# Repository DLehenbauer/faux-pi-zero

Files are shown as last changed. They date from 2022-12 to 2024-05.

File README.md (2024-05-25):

# Faux Pi Zero

Open hardware RP2040 dev board in a Raspberry Pi Zero compatible form factor.  Includes Mini HDMI (via [bitbanged DVI](https://github.com/Wren6991/PicoDVI)) and microSD.

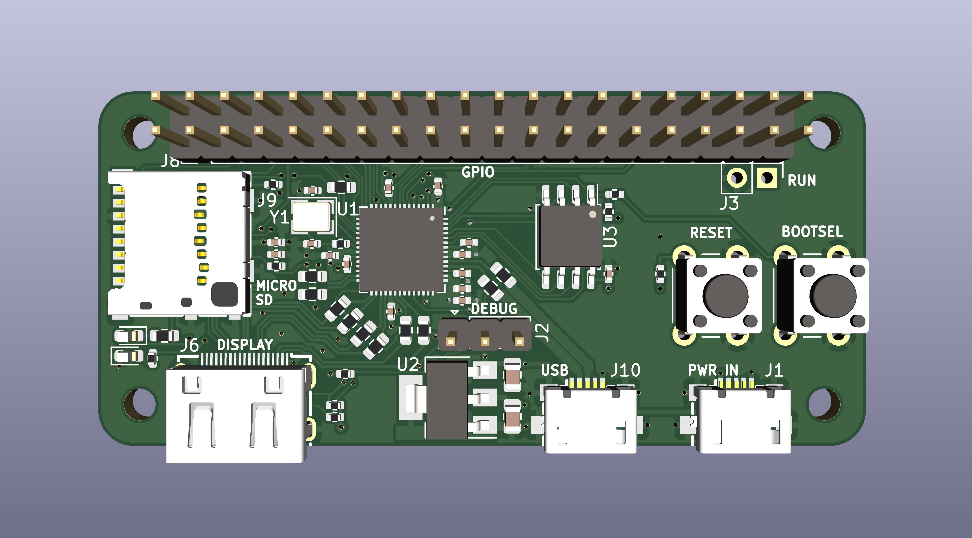
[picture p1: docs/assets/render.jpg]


## Description

This board aids with migrating a project from the Pi Zero to the RP2040 while retaining the option of moving back to the Pi Zero in the future.  It has the same footprint as the Pi Zero and a partially compatible [pinout](#pinout), making it convenient to support both the RP2040 and Pi Zero in the same design.

## Status

Works, but 1 of 2 boards received by JLCPCB had a solder bridge on the RP2040.  Looking at JLCPCB's EasyEDA footprints, it looks like JLCPCB used longer pads for the RP2040.  I'd recommend using a custom footprint and extending the pads, which hopefully will avoid defects.

A couple other things I'd change in retrospect:
* Expose UART TX/RX on the debug header and reorder pins so you can plug a [picoprobe](https://github.com/raspberrypi/picoprobe) into the board w/o wires.
* Remove the hacky activity LED from the microSD since [the lib](https://github.com/carlk3/no-OS-FatFS-SD-SPI-RPi-Pico) already blinks GP25.
* Try for a 2 layer board to reduce cost
* Reduce buttons to 6 x 3.5 and maybe try to squeeze in an optional wireless module

DVI and microSD both appear to work with a basic test.  I've exercised DVI, USB (host), SPI1, and the debug header quite a bit (all good).  Other functionality is either lightly tested or untested.

## Features

* Compatible footprint:
  * Mini HDMI (via [bitbanged DVI](https://github.com/Wren6991/PicoDVI))
  * Micro SD (via SPI mode.  Cards must be <2TB)
  * Micro USB
  * Power (via Micro USB)
* Partially compatible [pinout](#pinout)
* 16MB Flash
* Green status LED on GP25 (same as Pico)
* Red SD activity LED on GP9
* BOOTSEL and RESET buttons
* SWD Header

## Pinout

See [schematic](#schematic) for more details.



### Mapping from Pi Zero to Faux Px Zero

Pi Pin | Pico Pin | Pi GPIO | Pico GP | Function | Notes
-|-|-|-|-|-
1, 17 | 36 |  | 3V3 (Out) |  |
2, 4 | 39 |  | VSYS |  |
2, 4 | 40 |  | VBUS |  |
3 | 4 | GPIO 02 | GP 02 | I2C_SDA |
5 | 5 | GPIO 03 | GP 03 | I2C_SCL |
6, 9, 14, 20, 25, 30, 34, 39 | 3, 8, 13, 18, 23, 28, 33, 38, DBG-2 |  | GND |  |
7 |  | GPIO 04 | GP 24 |  |
8 | 1 | GPIO 14 | GP 00 | UART0 TX |
10 | 2 | GPIO 15 | GP 01 | UART0 RX |
11 | 12 | GPIO 17 | GP 09 | SD_CSn | Can be used as GP with SD card removed.  Note 10k pullup.
12 | 17 | GPIO 18 | GP 13 | SPI1_CSn | Can be used to share SPI1 with SD card.
13 | 11 | GPIO 27 | GP 08 | SD_DET | Can be used as GP with SD card removed.
15 | 14 | GPIO 22 | GP 10 | DVI_CEC | DVI_CEC when JP3 closed.  See [schematic](#schematic).
16 | 15 | GPIO 23 | GP 11 |  |
18 | DBG-3 | GPIO 24 | SWD |  |
19 | 6/10 | GPIO 10 | GP 04/07 | SPI0_RX/TX | Select [controller](https://www.oshwa.org/a-resolution-to-redefine-spi-signal-names/) or [peripheral](https://www.oshwa.org/a-resolution-to-redefine-spi-signal-names/) via JP1 and JP2.  See [schematic](#schematic).
21 | 10/6 | GPIO 09 | GP 07/04 | SPI0_TX/RX | Select [controller](https://www.oshwa.org/a-resolution-to-redefine-spi-signal-names/) or [peripheral](https://www.oshwa.org/a-resolution-to-redefine-spi-signal-names/) via JP1 and JP2.  See [schematic](#schematic).
22 | DBG-1 | GPIO 25 | SWCLK |  |
23 | 9 | GPIO 11 | GP 06 | SPI0_SCLK |
24 | 7 | GPIO 08 | GP 05 | SPI0_CSn |
26 |  | GPIO 07 |  |  |
27 | 34 | GPIO 00 | GP 28 | I2C_SCL | DVI_SDA when JP4 closed.  See [schematic](#schematic).
28 |  | GPIO 01 | GP 29 |  |
29 | 31 | GPIO 05 | GP 26 |  |
31 | 32 | GPIO 06 | GP 27 | I2C_SDA | DVI_SDA when JP5 closed.  See [schematic](#schematic).
32 |  | GPIO 12 |  |  |
33 |  | GPIO 13 |  |  |
35 | 16 | GPIO 19 | GP 12 | SPI1_RX / SD_DAT | Can be used as GP with SD card removed.  Note 10k pullup.
36 |  | GPIO 16 | BOOTSEL |  |
37 | 30 | GPIO 26 | RUN |  |
38 | 20 | GPIO 20 | GP 15 | SPI1_TX / SD_CMD | Can be used as GP with SD card removed.
40 | 19 | GPIO 21 | GP 14 | SPI1_SCLK / SD_CLK | Can be used as GP with SD card removed.
   |    |    | GP 23 | DVI_D2+ |
   |    | 21 | GP 16 | DVI_CK- |
   |    | 22 | GP 17 | DVI_CK+ |
   |    | 24 | GP 18 | DVI_D0- |
   |    | 25 | GP 19 | DVI_D0+ |
   |    | 26 | GP 20 | DVI_D1- |
   |    | 27 | GP 21 | DVI_D1+ |
   |    | 29 | GP 22 | DVI_D2- |
   | 35 |  | N/C |  |
   | 37 |  | 3V3_EN |  |
   | LED |  | GP 25 |  |

## Schematic

(Click image to view PDF)

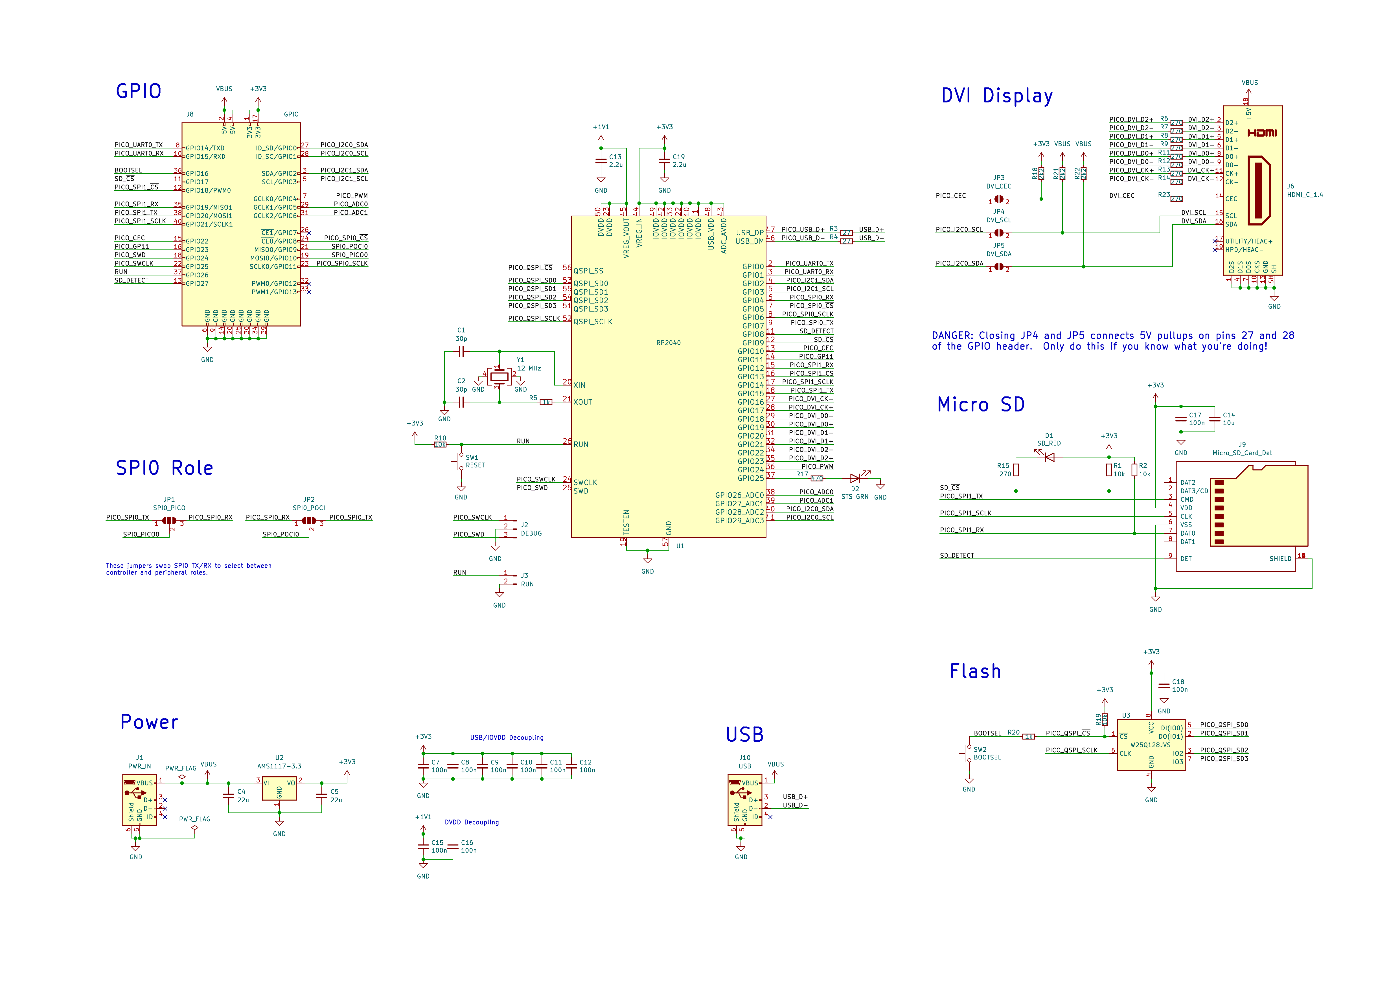
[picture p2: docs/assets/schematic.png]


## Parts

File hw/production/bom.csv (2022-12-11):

Designator | Footprint | Quantity | Value | LCSC Part #
C1, C2 | C_0402_1005Metric | 2 | 30p | C1570
C10, C11, C12, C15, C16, C17, C18, C7, C8, C9 | C_0402_1005Metric | 10 | 100n | C1525
C13, C19 | C_0402_1005Metric | 2 | 2.2u | C12530
C14 | C_0402_1005Metric | 1 | 10u | C15525
C4, C5 | C_0805_2012Metric | 2 | 22u | C45783
D1 | LED_0603_1608Metric | 1 | SD_RED | C2286
D2 | LED_0603_1608Metric | 1 | STS_GRN | C72043
J1 | MICRO-USB_MICRO-USB-17 | 1 | PWR_IN | C77238
J10 | MICRO-USB_MICRO-USB-17 | 1 | USB | C77238
J2 | PinHeader_1x03_P2.54mm_Vertical | 1 | DEBUG
J3 | PinHeader_1x02_P2.54mm_Vertical | 1 | RUN
J6 | HDMI-SMD_HDMI-201 | 1 | HDMI_C_1.4 | C720618
J8 | PinHeader_2x20_P2.54mm_Vertical | 1 | GPIO
J9 | SIM-SMD_8P-1040310811 | 1 | Micro_SD_Card_Det | C585350
JP1 | SolderJumper-3_P1.3mm_Open_RoundedPad1.0x1.5mm | 1 | SPI0_PICO
JP3 | SolderJumper-3_P1.3mm_Open_RoundedPad1.0x1.5mm | 1 | SPI0_POCI
JP7 | SolderJumper-2_P1.3mm_Open_RoundedPad1.0x1.5mm | 1 | DVI_CEC
JP8 | SolderJumper-2_P1.3mm_Open_RoundedPad1.0x1.5mm | 1 | DVI_SCL
JP9 | SolderJumper-2_P1.3mm_Open_RoundedPad1.0x1.5mm | 1 | DVI_SDA
R1, R10, R19, R2 | R_0402_1005Metric | 4 | 10k | C25744
R11, R12, R13, R14, R15, R23, R6, R7, R8, R9 | R_0603_1608Metric | 10 | 270 | C22966
R17 | R_0402_1005Metric | 1 | 470 | C25117
R18, R21, R22 | R_0402_1005Metric | 3 | 2k2 | C25879
R20, R5 | R_0402_1005Metric | 2 | 1k | C11702
R3, R4 | R_0603_1608Metric | 2 | 27 | C25190
SW1 | SW_PUSH_6mm | 1 | RESET
SW2 | SW_PUSH_6mm | 1 | BOOTSEL
U1 | QFN-56-1EP_7x7mm_P0.4mm_EP3.2x3.2mm_ThermalVias | 1 | RP2040 | C2040
U2 | SOT-223-3_TabPin2 | 1 | AMS1117-3.3 | C6186
U3 | SOIC-8_5.23x5.23mm_P1.27mm | 1 | W25Q128JVS | C97521
Y1 | Crystal_SMD_3225-4Pin_3.2x2.5mm | 1 | 12 MHz | C9002

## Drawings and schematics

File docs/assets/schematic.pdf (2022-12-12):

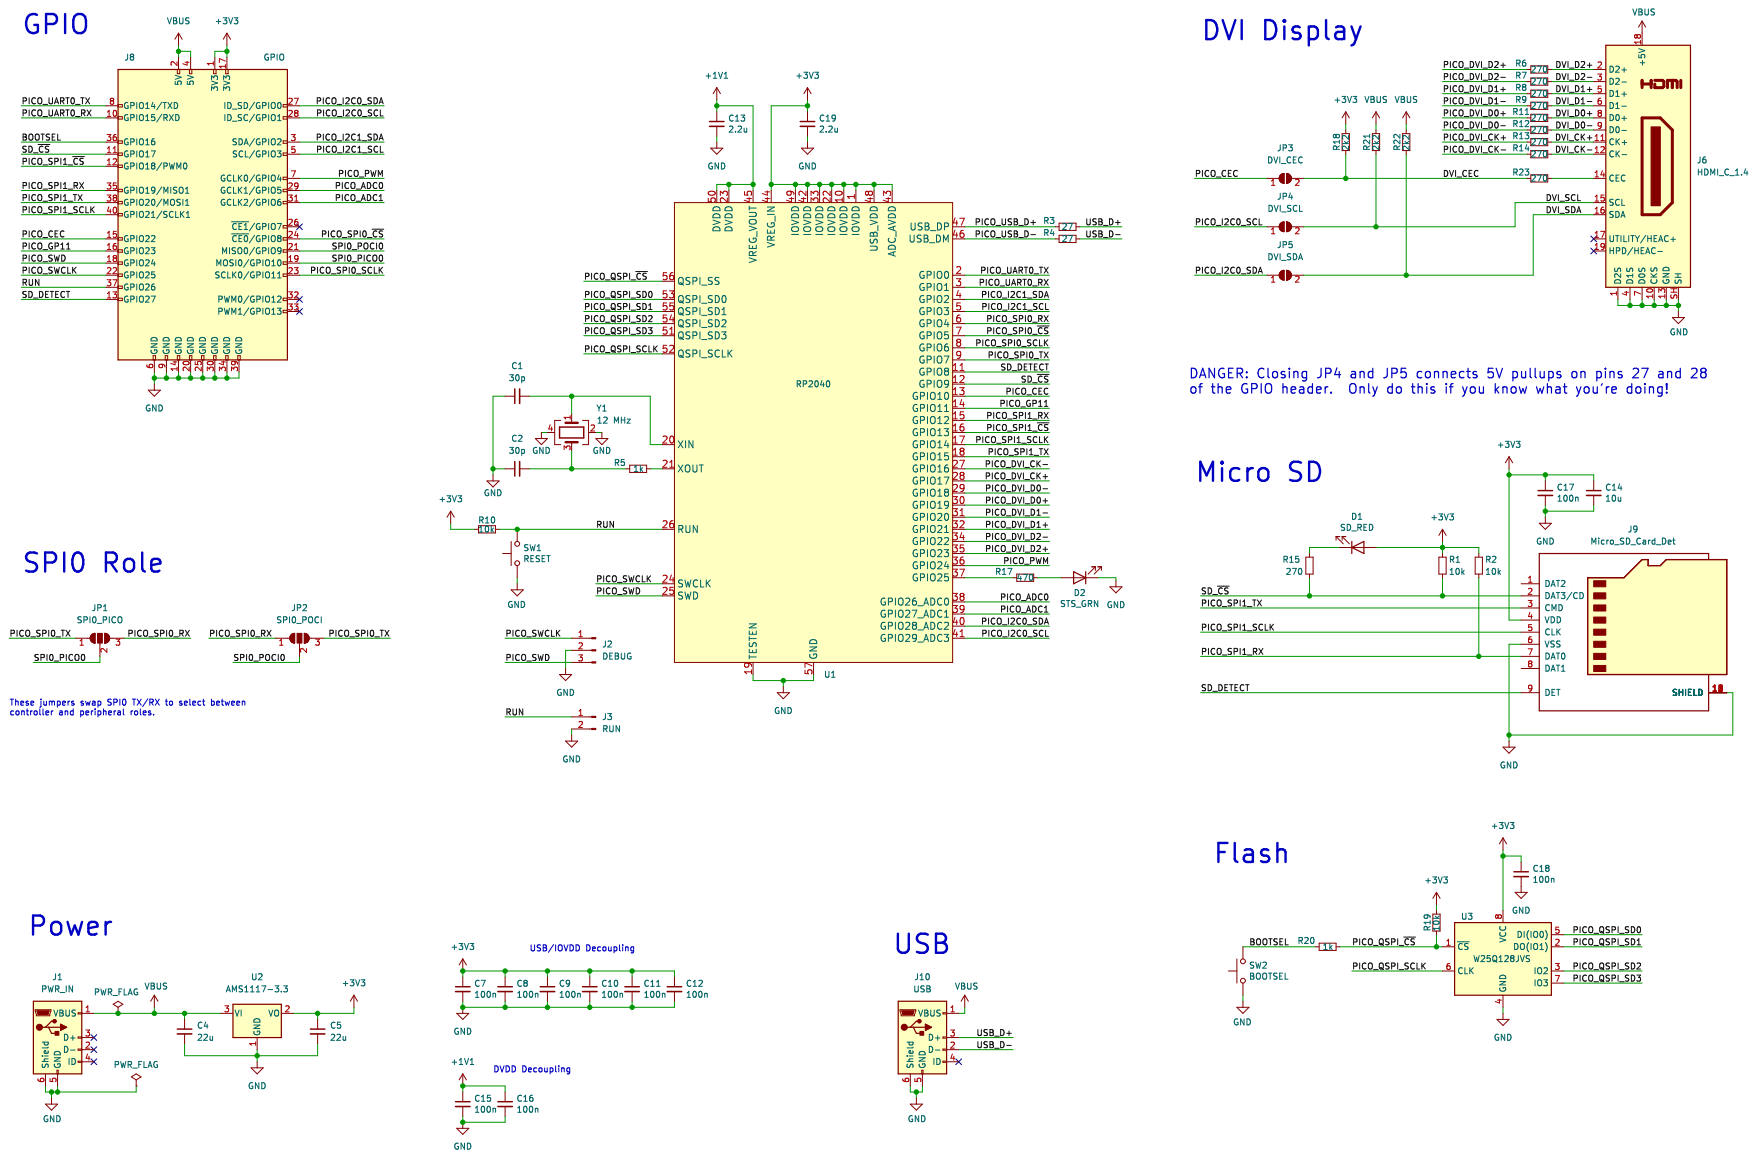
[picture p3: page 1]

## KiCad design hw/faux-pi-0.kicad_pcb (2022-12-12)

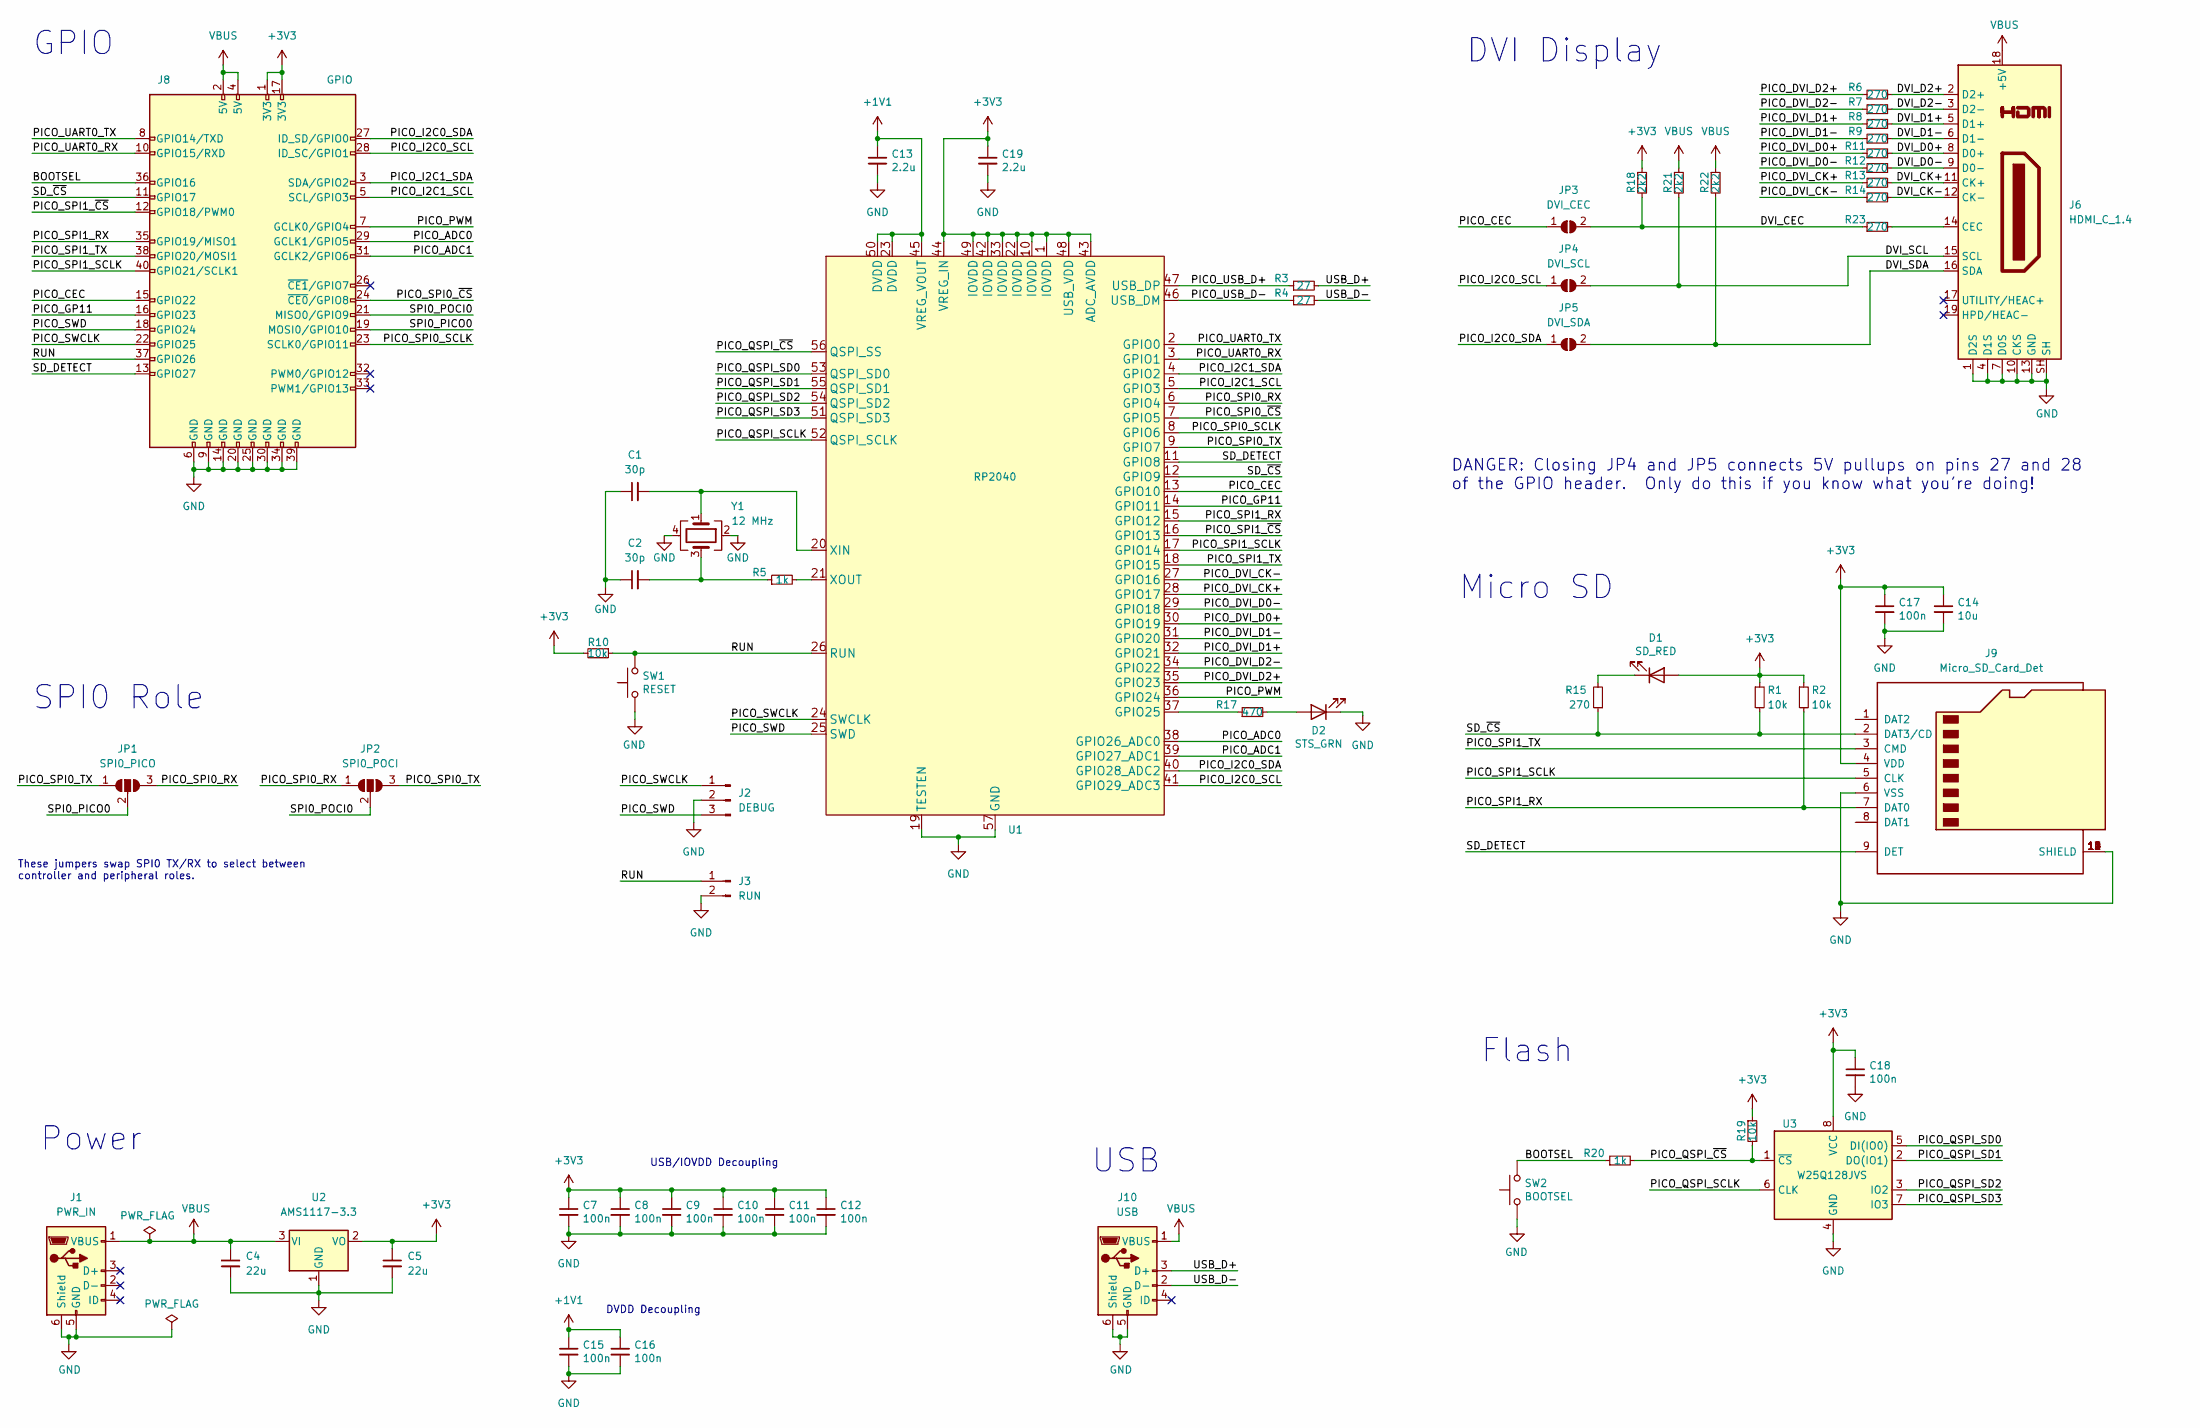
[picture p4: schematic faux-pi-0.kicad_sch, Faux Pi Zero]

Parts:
C1, C2: 30p; C_0402_1005Metric; LCSC C1570
C4, C5: 22u; C_0805_2012Metric; LCSC C45783
C7, C8, C9, C10, C11, C12, C15, C16, C17, C18: 100n; C_0402_1005Metric; LCSC C1525
C13, C19: 2.2u; C_0402_1005Metric; LCSC C12530
C14: 10u; C_0402_1005Metric; LCSC C15525
D1: SD_RED; LED_0603_1608Metric; LCSC C2286
D2: STS_GRN; LED_0603_1608Metric; LCSC C72043
J1: PWR_IN; MICRO-USB_MICRO-USB-17; LCSC C77238
J2: DEBUG; PinHeader_1x03_P2.54mm_Vertical
J3: RUN; PinHeader_1x02_P2.54mm_Vertical
J6: HDMI_C_1.4; HDMI-SMD_HDMI-201; LCSC C720618
J8: GPIO; PinHeader_2x20_P2.54mm_Vertical
J9: Micro_SD_Card_Det; SIM-SMD_8P-1040310811; LCSC C585350
J10: USB; MICRO-USB_MICRO-USB-17; LCSC C77238
JP1: SPI0_PICO; SolderJumper-3_P1.3mm_Open_RoundedPad1.0x1.5mm
JP2: SPI0_POCI; SolderJumper-3_P1.3mm_Open_RoundedPad1.0x1.5mm
JP3: DVI_CEC; SolderJumper-2_P1.3mm_Open_RoundedPad1.0x1.5mm
JP4: DVI_SCL; SolderJumper-2_P1.3mm_Open_RoundedPad1.0x1.5mm
JP5: DVI_SDA; SolderJumper-2_P1.3mm_Open_RoundedPad1.0x1.5mm
R1, R2, R10, R19: 10k; R_0402_1005Metric; LCSC C25744
R3, R4: 27; R_0603_1608Metric; LCSC C25190
R5, R20: 1k; R_0402_1005Metric; LCSC C11702
R6, R7, R8, R9, R11, R12, R13, R14, R15, R23: 270; R_0603_1608Metric; LCSC C22966
R17: 470; R_0402_1005Metric; LCSC C25117
R18, R21, R22: 2k2; R_0402_1005Metric; LCSC C25879
SW1: RESET; SW_PUSH_6mm
SW2: BOOTSEL; SW_PUSH_6mm
U1: RP2040; QFN-56-1EP_7x7mm_P0.4mm_EP3.2x3.2mm_ThermalVias; LCSC C2040
U2: AMS1117-3.3; SOT-223-3_TabPin2; LCSC C6186
U3: W25Q128JVS; SOIC-8_5.23x5.23mm_P1.27mm; LCSC C97521
Y1: 12 MHz; Crystal_SMD_3225-4Pin_3.2x2.5mm; LCSC C9002

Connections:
+1V1: C13.1, C15.1, C16.1, U1.23 (DVDD), U1.45 (VREG_VOUT), U1.50 (DVDD)
+3V3: C5.1, C7.1, C8.1, C9.1, C10.1, C11.1, C12.1, C14.1, C17.1, C18.1, C19.1, D1.2 (A), J8.1 (3V3), J8.17 (3V3), J9.4 (VDD), R1.1, R2.1, R10.2, R18.1, R19.1, U1.1 (IOVDD), U1.10 (IOVDD), U1.22 (IOVDD), U1.33 (IOVDD), U1.42 (IOVDD), U1.43 (ADC_AVDD), U1.44 (VREG_IN), U1.48 (USB_VDD), U1.49 (IOVDD), U2.2 (VO), U3.8 (VCC)
/BOOTSEL: J8.36 (GPIO16), R20.1, SW2.2
/DVI_CEC: JP3.2 (B), R18.2, R23.1
/DVI_CK+: J6.11 (CK+), R13.2
/DVI_CK-: J6.12 (CK-), R14.2
/DVI_D0+: J6.8 (D0+), R11.2
/DVI_D0-: J6.9 (D0-), R12.2
/DVI_D1+: J6.5 (D1+), R8.2
/DVI_D1-: J6.6 (D1-), R9.2
/DVI_D2+: J6.2 (D2+), R6.2
/DVI_D2-: J6.3 (D2-), R7.2
/DVI_SCL: J6.15 (SCL), JP4.2 (B), R21.2
/DVI_SDA: J6.16 (SDA), JP5.2 (B), R22.2
/PICO_ADC0: J8.29 (GCLK1/GPIO5), U1.38 (GPIO26_ADC0)
/PICO_ADC1: J8.31 (GCLK2/GPIO6), U1.39 (GPIO27_ADC1)
/PICO_CEC: J8.15 (GPIO22), JP3.1 (A), U1.13 (GPIO10)
/PICO_DVI_CK+: R13.1, U1.28 (GPIO17)
/PICO_DVI_CK-: R14.1, U1.27 (GPIO16)
/PICO_DVI_D0+: R11.1, U1.30 (GPIO19)
/PICO_DVI_D0-: R12.1, U1.29 (GPIO18)
/PICO_DVI_D1+: R8.1, U1.32 (GPIO21)
/PICO_DVI_D1-: R9.1, U1.31 (GPIO20)
/PICO_DVI_D2+: R6.1, U1.35 (GPIO23)
/PICO_DVI_D2-: R7.1, U1.34 (GPIO22)
/PICO_GP11: J8.16 (GPIO23), U1.14 (GPIO11)
/PICO_I2C0_SCL: J8.28 (ID_SC/GPIO1), JP4.1 (A), U1.41 (GPIO29_ADC3)
/PICO_I2C0_SDA: J8.27 (ID_SD/GPIO0), JP5.1 (A), U1.40 (GPIO28_ADC2)
/PICO_I2C1_SCL: J8.5 (SCL/GPIO3), U1.5 (GPIO3)
/PICO_I2C1_SDA: J8.3 (SDA/GPIO2), U1.4 (GPIO2)
/PICO_PWM: J8.7 (GCLK0/GPIO4), U1.36 (GPIO24)
/PICO_QSPI_SCLK: U1.52 (QSPI_SCLK), U3.6 (CLK)
/PICO_QSPI_SD0: U1.53 (QSPI_SD0), U3.5 (DI(IO0))
/PICO_QSPI_SD1: U1.55 (QSPI_SD1), U3.2 (DO(IO1))
/PICO_QSPI_SD2: U1.54 (QSPI_SD2), U3.3 (IO2)
/PICO_QSPI_SD3: U1.51 (QSPI_SD3), U3.7 (IO3)
/PICO_QSPI_~CS: R19.2, R20.2, U1.56 (QSPI_SS), U3.1 (~CS)
/PICO_SPI0_RX: JP1.3 (B), JP2.1 (A), U1.6 (GPIO4)
/PICO_SPI0_SCLK: J8.23 (SCLK0/GPIO11), U1.8 (GPIO6)
/PICO_SPI0_TX: JP1.1 (A), JP2.3 (B), U1.9 (GPIO7)
/PICO_SPI0_~CS: J8.24 (~CE0/GPIO8), U1.7 (GPIO5)
/PICO_SPI1_RX: J8.35 (GPIO19/MISO1), J9.7 (DAT0), R2.2, U1.15 (GPIO12)
/PICO_SPI1_SCLK: J8.40 (GPIO21/SCLK1), J9.5 (CLK), U1.17 (GPIO14)
/PICO_SPI1_TX: J8.38 (GPIO20/MOSI1), J9.3 (CMD), U1.18 (GPIO15)
/PICO_SPI1_~CS: J8.12 (GPIO18/PWM0), U1.16 (GPIO13)
/PICO_SWCLK: J2.1, J8.22 (GPIO25), U1.24 (SWCLK)
/PICO_SWD: J2.3, J8.18 (GPIO24), U1.25 (SWD)
/PICO_UART0_RX: J8.10 (GPIO15/RXD), U1.3 (GPIO1)
/PICO_UART0_TX: J8.8 (GPIO14/TXD), U1.2 (GPIO0)
/PICO_USB_D+: R3.1, U1.47 (USB_DP)
/PICO_USB_D-: R4.1, U1.46 (USB_DM)
/RUN: J3.1, J8.37 (GPIO26), R10.1, SW1.2, U1.26 (RUN)
/SD_DETECT: J8.13 (GPIO27), J9.9 (DET), U1.11 (GPIO8)
/SD_~CS: J8.11 (GPIO17), J9.2 (DAT3/CD), R1.2, R15.1, U1.12 (GPIO9)
/SPI0_PICO0: J8.19 (MOSI0/GPIO10), JP1.2 (C)
/SPI0_POCI0: J8.21 (MISO0/GPIO9), JP2.2 (C)
/USB_D+: J10.3 (D+), R3.2
/USB_D-: J10.2 (D-), R4.2
GND: C1.1, C2.1, C4.2, C5.2, C7.2, C8.2, C9.2, C10.2, C11.2, C12.2, C13.2, C14.2, C15.2, C16.2, C17.2, C18.2, C19.2, D2.1 (K), J1.5 (GND), J1.6 (Shield), J2.2, J3.2, J6.1 (D2S), J6.4 (D1S), J6.7 (D0S), J6.10 (CKS), J6.13 (GND), J6.SH, J8.6 (GND), J8.9 (GND), J8.14 (GND), J8.20 (GND), J8.25 (GND), J8.30 (GND), J8.34 (GND), J8.39 (GND), J9.6 (VSS), J9.10 (SHIELD), J9.11 (SHIELD), J9.12 (SHIELD), J9.13 (SHIELD), J9.14 (SHIELD), J10.5 (GND), J10.6 (Shield), SW1.1, SW2.1, U1.19 (TESTEN), U1.57 (GND), U2.1 (GND), U3.4 (GND), Y1.2, Y1.4
unnamed: C1.2, U1.20 (XIN), Y1.1
unnamed: C2.2, R5.1, Y1.3
unnamed: D1.1 (K), R15.2
unnamed: D2.2 (A), R17.2
unnamed: J6.14 (CEC), R23.2
unnamed: R5.2, U1.21 (XOUT)
unnamed: R17.1, U1.37 (GPIO25)
VBUS: C4.1, J1.1 (VBUS), J6.18 (+5V), J8.2 (5V), J8.4 (5V), J10.1 (VBUS), R21.1, R22.1, U2.3 (VI)

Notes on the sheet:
These jumpers swap SPI0 TX/RX to select between controller and peripheral roles.
DANGER: Closing JP4 and JP5 connects 5V pullups on pins 27 and 28 of the GPIO header. Only do this if you know what you're doing!
USB/IOVDD Decoupling
Flash
USB
GPIO
SPI0 Role
DVI Display
DVDD Decoupling
Power
Micro SD

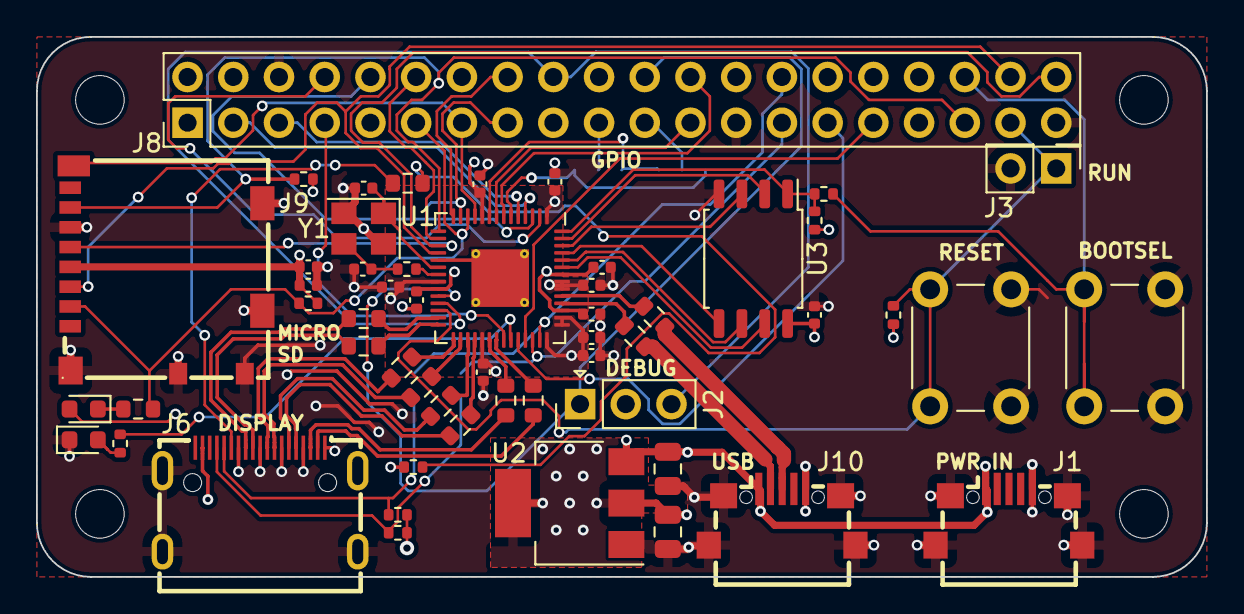
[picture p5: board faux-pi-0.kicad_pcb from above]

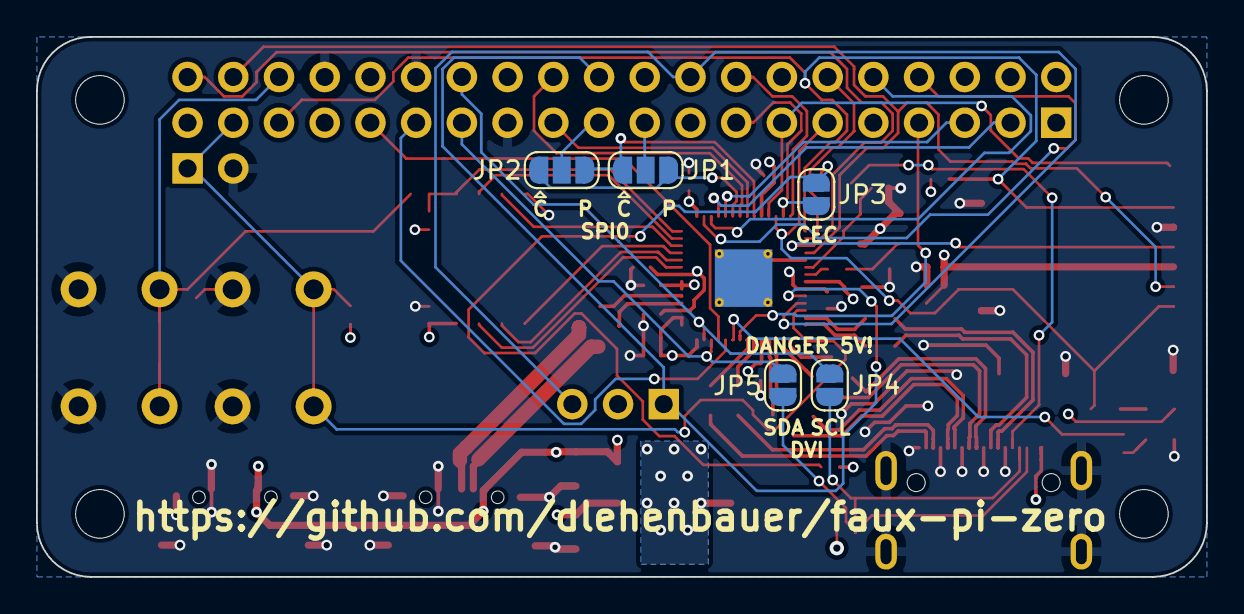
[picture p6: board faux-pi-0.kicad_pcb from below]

Board: 4 copper layers, 65.0 x 30.0 mm, 63 parts (5 on the bottom side), 67 nets.

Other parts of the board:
MH1, MH2, MH3, MH4: MountingHole_2.7mm_M2.5

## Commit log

2022-12-11 Expose BOOTSEL and RUN on GPIO header
    [faux-pi-0.kicad_pcb, faux-pi-0.kicad_sch]
2022-12-11 docs & remove UART jumpers
    [faux-pi-0.kicad_pcb, faux-pi-0.kicad_sch]
2022-12-11 Add production files for JLCPCB
    [bom.csv, designators.csv, positions.csv]
